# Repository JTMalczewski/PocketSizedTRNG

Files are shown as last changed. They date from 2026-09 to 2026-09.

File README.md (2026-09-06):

# Pocket-sized True Random Number Generator using weak radioactive source
Pocket-sized True Random Number Generator leverages radiation decay measured by a Geiger counter to produce high-quality entropy. The device processes these random physical events into cryptographically useful bitstreams directly on an RP2040 microcontroller - Raspberry Pi Pico H.

### Repository content

* `/models`: 3d-models used for printing devices case and double walled box for the radioactive isotope.

* `/code`: Full CircutPython code used in the device.

* `/sp800_22_tests`: implementation of the NIST SP800-22 Rev1a tests suite in python created by [dj-on-github](https://github.com/dj-on-github).

* `/data`: Samples of the random sequences generated by the device.

### Hardware configuration

* **Output**: Random data is piped securely to a host device over a USB CDC data connection.

* **Geiger Counter Interface**: Uses the RP2040's Programmable I/O (PIO) on pin GP0. A dedicated state machine runs at 100 MHz to measure the clock cycles between incoming radiation pulses. Device detects background radiation or radioactive isotope by Gravity Geiger Counter SEN0463 but any other detector that lowers the voltage on event detection will work.

* **Real-Time Clock and Local Storage**: An integrated Adafruit PiCowbell Adalogger with PCF8523 RTC module and SD slot communicates 
* * via I2C - pins GP4 and GP5 to timestamp logs and provide nonce to DRBG 
* * via GP16, GP17, GP18, GP19 to allow headless data collection.

### Entropy extraction & calibration

* **Von Neumann Debiasing**: An optional software flag applies a Von Neumann extractor to the raw interval bits, eliminating bias in older bits of the counter.

* **SD Logging**: The system can write raw cycle data and interval timestamps to a SD card for offline randomness collection.

* **TRNG**: Device can send generated bytes via USB port to be used as an entropy source to the operating system or to be gathered in a file.

### Cryptography & self-testing

* **Hash DRBG**: The device can optionally feed a built-in Deterministic Random Bit Generator. It gathers 55 bytes of pure entropy to seed the generator, outputting data in 1024-byte chunks.

* **Embedded Statistical Tests**: Implements on-the-fly health checks using Monobit, Frequency within Block, Runs, Longest Run, Serial, Approximate Entropy, and Cumulative Sums tests from NIST SP800-22 Rev1a test suite.

## Reading random bytes on Linux
Since the `boot.py` file enables both the console and the data channel (`usb_cdc.enable(console=True, data=True)`), the microcontroller will expose two separate serial ports when connected.

### 1. Identify the data port

After plugging in the device, open your terminal and list the connected serial devices:

```bash
ls -l /dev/ttyACM*
```

You will typically see two devices listed:

`/dev/ttyACM0` – The REPL console

`/dev/ttyACM1` – The data channel

### 2. Configure permissions and add packages

- Add your user to the dialout group. You must log out and log back in (or restart your computer) for this change to take effect.
```Bash
sudo usermod -aG dialout $USER
```
- Script below uses `serial` package. You can install it by running:
```bash
pip install pyserial
```

### 3. Read and print the data

Create a script with the following code to listen to the data channel and print the received bytes.
```py
Python

import serial

PORT = '/dev/ttyACM1' 
BAUDRATE = 115200 

try:
    with serial.Serial(PORT, BAUDRATE, timeout=1) as ser:
        print(f"Opened port {PORT}. Waiting for entropy from the Geiger counter...")
        
        while True:
            byte_data = ser.read(1)
            
            if byte_data:
                hex_val = byte_data.hex()
                int_val = int.from_bytes(byte_data, byteorder='big')
                print(f"Received byte: 0x{hex_val} (Dec: {int_val})")
                
except serial.SerialException as e:
    print(f"Serial port error: {e}")
except KeyboardInterrupt:
    print("\nStopped listening.")
```

### 4. Save the data
You can run the attached script using default settings to immediately start saving raw binary data to your working directory:

```bash
python read_bytes.py
```

**Command-Line Arguments**

| Argument | Short Flag | Description | Default Value |
| --- | --- | --- | --- |
| `--port` | `-p` | Defines the serial port the Geiger counter is connected to. | `/dev/ttyACM1`<br> |
| `--baudrate` | `-b` | Sets the serial baud rate. | `115200`<br> |
| `--output` | `-o` | Specifies the destination file path for the saved data. | `random_bytes.bin`<br> |
| `--format` | `-f` | Determines how the bytes are encoded in the output file. | `bin`<br> |
| `--verbose` | `-v` | Prints the hex and decimal values of each gathered byte to the console. | Disabled |

**Supported Output Formats (`-f`)**

* **`bin`**: Writes the raw binary byte stream to the file.
* **`hex`**: Converts the bytes into hexadecimal digits, outputting them at 32 bytes per line.
* **`asci`**: Maps the random bytes to printable ASCII characters (`chr(32 + (b % 95)`), saving 32 characters per line.
* **`dec`**: Outputs space-separated decimal numbers, formatting them with 16 values per line.
* **`bits`**: Saves the data as literal binary strings (0s and 1s), writing 8 bytes per line.

**Stopping the Capture**
The script will wait and listen for data indefinitely. Press `Ctrl+C` in your terminal to stop the process. The script will automatically flush any remaining buffered text data to your output file before exiting.

### 5. Test the randomness
 To perform full analysis on generated sequence run:
```bash
./sp800_22_tests/sp800_22_tests.py ./data/random_bytes.bin
```

## Feeding TRNG entropy to the Linux kernel
You can feed randomness directly into the Linux kernel to improve system cryptography using either a Python script or the standard Linux `rng-tools` daemon.

### Method 1: Python script

To increase the kernel's entropy pool, data must be injected using the `RNDADDENTROPY` system call. The following script batches the bytes from the serial port and injects them into `/dev/random`.

**Prerequisites:** You must run this script with `sudo` or as root.

```python
import serial
import fcntl
import struct

PORT = '/dev/ttyACM1' 
BAUDRATE = 115200 

# The ioctl code for RNDADDENTROPY on x86, x86_64, and ARM Linux
RNDADDENTROPY = 0x40085203 

try:
    dev_random = open('/dev/random', 'wb')
except PermissionError:
    print("Error: You must run this script as root to inject entropy.")
    exit(1)

try:
    with serial.Serial(PORT, BAUDRATE, timeout=1) as ser:
        print(f"Opened port {PORT}. Gathering entropy from Geiger counter...")
        
        buffer = b''
        chunk_size = 32
        while True:
            byte_data = ser.read(1)
            if byte_data:
                buffer += byte_data
                if len(buffer) >= chunk_size:
                    entropy_bits = len(buffer) * 8
                    buf_size = len(buffer)
                    fmt = f'ii{buf_size}s'
                    payload = struct.pack(fmt, entropy_bits, buf_size, buffer)
                    fcntl.ioctl(dev_random, RNDADDENTROPY, payload)
                    print(f"Injected {buf_size} bytes ({entropy_bits} bits of entropy) into the kernel.")
                    buffer = b''
                
except serial.SerialException as e:
    print(f"Serial port error: {e}")
except KeyboardInterrupt:
    print("\nStopped listening.")
finally:
    dev_random.close()
```

### Method 2: Using rngd

For long-term or production use, the standard Linux rngd (from rng-tools) is recommended. It runs continuously in the background and constantly performs FIPS 140-2 cryptographic tests on the incoming data stream to ensure the sensor hasn't failed or become biased.

#### 1. Install rng-tools:
```Bash

# Debian/Ubuntu
sudo apt install rng-tools

# RHEL/Fedora
sudo dnf install rng-tools
```
#### 2. Configure the serial port:
Set the correct baud rate and tell Linux not to parse the raw binary data for terminal control characters.

```Bash
sudo stty -F /dev/ttyACM1 115200 raw -echo
```
3. Run the Daemon:
Tell rngd to use the serial port as the hardware RNG source.
```Bash
sudo rngd -r /dev/ttyACM1 -f -v
```
(Omit the -f and -v flags to let it run silently in the background as a standard daemon).

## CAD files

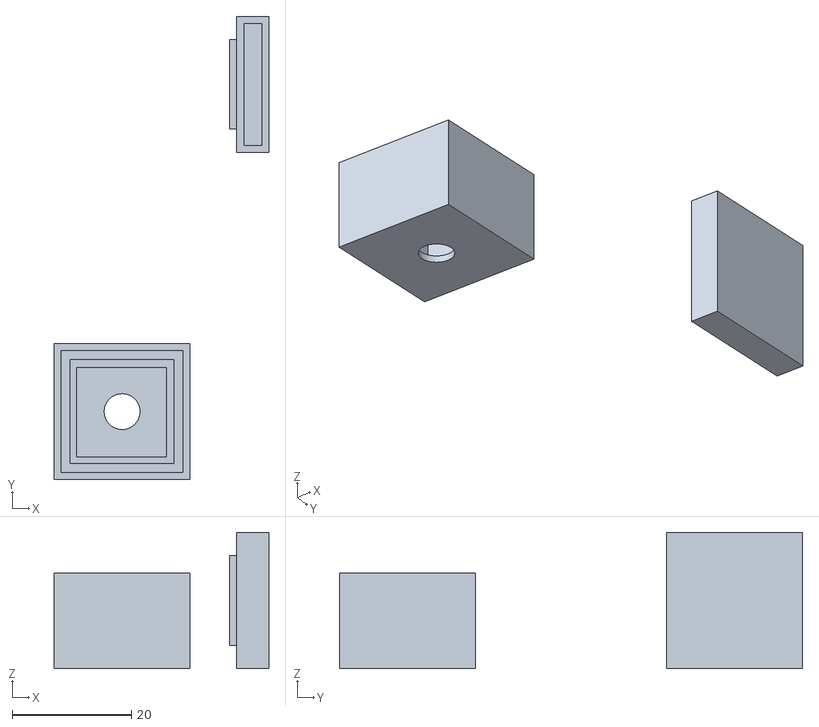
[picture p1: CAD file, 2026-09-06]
models/Isotop_container.stl
36.0 x 77.6 x 22.8

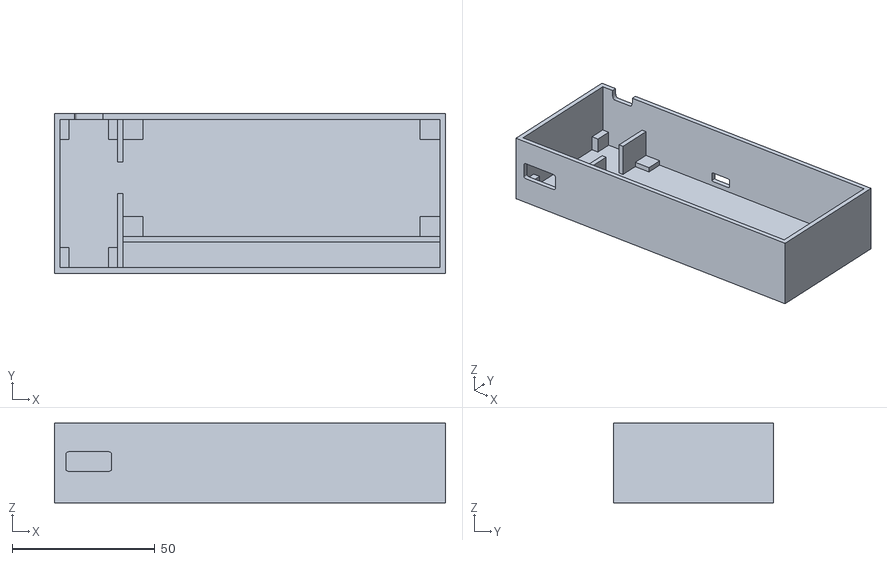
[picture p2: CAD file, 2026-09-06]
models/Gaiger_box.stl
137.0 x 56.0 x 28.0

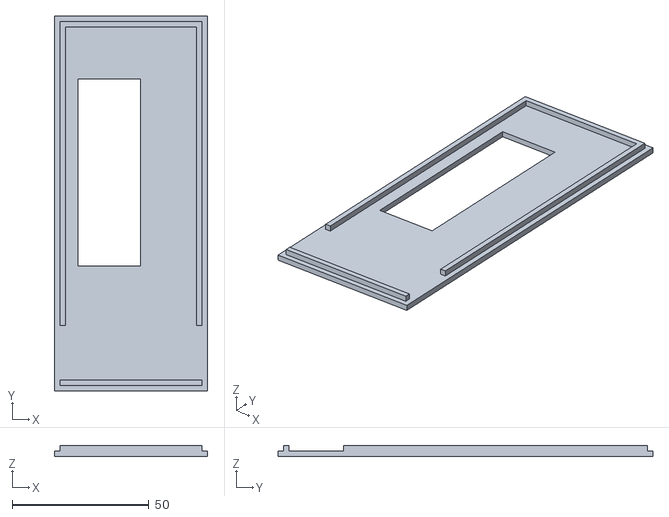
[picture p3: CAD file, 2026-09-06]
models/Gaiger_lid.stl
56.0 x 137.0 x 4.00

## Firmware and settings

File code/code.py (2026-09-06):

# SPDX-FileCopyrightText: 2017 ladyada for Adafruit Industries
# SPDX-License-Identifier: MIT

import time
import board
import busio
import rp2pio
import storage
import sdcardio
import array
from adafruit_pcf8523.pcf8523 import PCF8523
import digitalio
import sys
import usb_cdc
import monobit
import frequency_within_block
import runs
import longest_run
import serial
import approximate_entropy
import cumulative_sums
import HashDRBGMicro

# -------- Settings --------
VON_NEUMANN = True
WRITING = False
TRNG = True
TRNG_WRITING = False
LOGFILE = "/sd/Izotop_test_02_08_2026.csv"
TRNG_BIN_FILE = "/sd/TRND.bin"
CALIBRATION = False
BITS_TO_EXTRACT = 32

# -------- Test Settings --------
# TEST_MODE options:
# "NONE"     -> Tests disabled, data flows immediately without blocking.
# "INTERVAL" -> Run tests periodically every TEST_INTERVAL_BYTES generated.
# "RESEED"   -> Run tests every time before DRBG is instantiated or reseeded.
TEST_MODE = "RESEED"
TEST_INTERVAL_BYTES = 10000
N_BITS_TO_CHECK = 1000

# -------- DRBG settings --------
USE_DRBG = True
DRBG_ENTROPY_REQUIRED = 55
DRBG_OUTPUT_BYTES = 1024
PERSONALIZATION_STRING = b"Izotop_RP2040_TRNG_v1"
RESEED_INTERVAL = 1000

# -------- SD Card --------
SD_CS = board.GP17
spi = busio.SPI(board.GP18, board.GP19, board.GP16)
sdcard = sdcardio.SDCard(spi, SD_CS)
vfs = storage.VfsFat(sdcard)

if WRITING or TRNG_WRITING:
    try:
        storage.mount(vfs, "/sd")
        print("sd card mounted")
    except ValueError:
        print("no SD card")

# -------- Time --------
I2C = busio.I2C(board.GP5, board.GP4)
rtc = PCF8523(I2C)
set_time = False
t = rtc.datetime
days = ("Sunday", "Monday", "Tuesday", "Wednesday", "Thursday", "Friday", "Saturday")
if set_time:   # change to True if you want to write the time!
    #                     year, mon, date, hour, min, sec, wday, yday, isdst
    t = time.struct_time((2025,  12,   9,   22,  33,  25,    1,   -1,    -1))

    print("Setting time to:", t)
    rtc.datetime = t
    print()

def rtc_timestamp(rtc):
    t = rtc.datetime
    return (
        f"{t.tm_year:04d}-{t.tm_mon:02d}-{t.tm_mday:02d},"
        f"{t.tm_hour:02d}:{t.tm_min:02d}:{t.tm_sec:02d}"
    )

# -------- Logs --------
#  initial write to the SD card on startup
if WRITING:
    try:
        with open("/sd/temp.txt", "a") as f:
            f.write('The date is {} {}/{}/{}\n'.format(days[t.tm_wday], t.tm_mon, t.tm_mday, t.tm_year))
            f.write('Start time: {}:{}:{}\n'.format(t.tm_hour, t.tm_min, t.tm_sec))
            f.write('Temp,Time\n')
            print("initial write to SD card complete, starting to log")
    except ValueError:
        print("initial write to SD card failed - check card")


# -------- Gaiger Configuration --------
period_between_lows_bin = array.array("H", [
    0xa02b, # 0: mov x, !null
    # --- MAIN LOOP ---
    0x00c6, # 1: jmp pin, 6

    # --- IF LOW SIGNAL DETECTED ---
    0xa0c1, # 2: mov isr, x
    0x8020, # 3: push
    0xa02b, # 4: mov x, !null
    0x20a0, # 5: wait 1 pin 0

    # --- COUNTING ---
    0x0041, # 6: jmp x--, 1
])

# - For 100 MHz (1 loop = 1 us)
# - unsigned 32-int counter: 4294967294
# - one loop takes 2 clock ticks
# - overflow after 86 s

measure = rp2pio.StateMachine(
    period_between_lows_bin,
    frequency=100_000_000,
    first_in_pin=board.GP0,
    jmp_pin=board.GP0,
    in_pin_count=1
)

buf = array.array("I", [0])

# -------- TRNG --------
_entropy_byte = 0
_bit_count = 0
_vn_prev_cycles = None

def get_entropy_bytes_and_bits(cycles, num_bits):
    global _entropy_byte, _bit_count, _vn_prev_cycles
    completed_bytes = []
    valid_bits = []

    if VON_NEUMANN:
        if _vn_prev_cycles is None:
            _vn_prev_cycles = cycles
        else:
            for i in range(num_bits):
                b1 = (_vn_prev_cycles >> i) & 1
                b2 = (cycles >> i) & 1

                valid_bit = None
                if b1 == 0 and b2 == 1:
                    valid_bit = 0
                elif b1 == 1 and b2 == 0:
                    valid_bit = 1

                if valid_bit is not None:
                    _entropy_byte = (_entropy_byte << 1) | valid_bit
                    _bit_count += 1
                    valid_bits.append(valid_bit)

                    if _bit_count == 8:
                        completed_bytes.append(_entropy_byte)
                        _entropy_byte = 0
                        _bit_count = 0

            _vn_prev_cycles = None
    else:
        for i in range(num_bits):
            bit = (cycles >> i) & 1
            _entropy_byte = (_entropy_byte << 1) | bit
            _bit_count += 1
            valid_bits.append(bit)

            if _bit_count == 8:
                completed_bytes.append(_entropy_byte)
                _entropy_byte = 0
                _bit_count = 0

    return completed_bytes, valid_bits


def run_all_tests(bits_to_test):
    print(f"\n--- Running tests ({len(bits_to_test)} bits) ---")

    success_mb, p, _ = monobit.monobit_test(bits_to_test)
    print(f"-> Monobit Result: {'PASSED' if success_mb else 'FAILED'} (p-value: {p:.5f})")

    success_blk, p_blk, _ = frequency_within_block.frequency_within_block_test(bits_to_test)
    print(f"-> Freq Within Block Result: {'PASSED' if success_blk else 'FAILED'} (p-value: {p_blk:.5f})")

    success_runs, p_runs, _ = runs.runs_test(bits_to_test)
    print(f"-> Runs Result: {'PASSED' if success_runs else 'FAILED'} (p-value: {p_runs:.5f})")

    success_lr, p_lr, _ = longest_run.longest_run_ones_in_a_block_test(bits_to_test)
    print(f"-> Longest Run Result: {'PASSED' if success_lr else 'FAILED'} (p-value: {p_lr:.5f})")

    success_serial, _, p_list_serial = serial.serial_test(bits_to_test)
    print(f"-> Serial Result: {'PASSED' if success_serial else 'FAILED'} (P1: {p_list_serial[0]:.5f}, P2: {p_list_serial[1]:.5f})")

    success_ae, p_ae, _ = approximate_entropy.approximate_entropy_test(bits_to_test)
    print(f"-> Approx Entropy Result: {'PASSED' if success_ae else 'FAILED'} (p-value: {p_ae:.5f})")

    success_cusum, _, p_list_cusum = cumulative_sums.cumulative_sums_test(bits_to_test)
    print(f"-> Cumulative Sums Result: {'PASSED' if success_cusum else 'FAILED'} (Fwd: {p_list_cusum[0]:.5f}, Bwd: {p_list_cusum[1]:.5f})")

    print("-----------------------------------------\n")
    return (success_mb and success_blk and success_runs and success_lr and
            success_serial and success_ae and success_cusum)

# -------- TRNG Calibration --------
if CALIBRATION:
    print("Starting calibration - counting pulses for 10 seconds (RTC)...")
    total_cycles = 0
    counts = 0

    while measure.in_waiting:
        measure.readinto(buf)

    start_time = time.mktime(rtc.datetime)
    current_time = start_time

    while (current_time - start_time) < 10:
        if measure.in_waiting:
            measure.readinto(buf)
            raw_value = buf[0]
            max_uint32 = 0xFFFFFFFF
            total_cycles += (max_uint32 - raw_value)
            counts += 1
        else:
            current_time = time.mktime(rtc.datetime)

    if counts > 0:
        avg_cycles = total_cycles // counts
        print(f"Calibration finished. {counts} pulses recorded.")
        print(f"Average number of cycles between pulses: {avg_cycles}")
    else:
        avg_cycles = 100_000_000
        print("No pulses during calibration. Assuming background radiation.")

    if avg_cycles < 50_000:
        BITS_TO_EXTRACT = 6
    elif avg_cycles < 500_000:
        BITS_TO_EXTRACT = 6
    elif avg_cycles < 5_000_000:
        BITS_TO_EXTRACT = 8
    else:
        BITS_TO_EXTRACT = 8

    print(f"Set to extract {BITS_TO_EXTRACT} bits from each read.")
else:
    print(f"Calibration skipped. Defaulted to {BITS_TO_EXTRACT} bits extraction.")

# -------- DRBG Setup --------
if USE_DRBG:
    drbg = HashDRBGMicro.HashDRBGMicro()
drbg_is_seeded = False
raw_entropy_buffer = bytearray(DRBG_ENTROPY_REQUIRED)
entropy_index = 0

# -------- Main State --------
log_buffer = ""
trng_buffer = bytearray()
last_save_time = time.monotonic()
SAVE_INTERVAL = 5.0

# Testing state variables
testing_active = False
bytes_since_last_test = 0
reseed_test_passed = False
test_bit_buffer = []

if WRITING:
    try:
        with open(LOGFILE, "a") as f:
            if f.tell() == 0:
                f.write("date,time,cycles,delta_ns\n")
    except Exception as e:
        print("SD init error for CSV:", e)

if TRNG_WRITING:
    print("Writing TRNG bytes to BIN file activated.")

print("I'm starting to collect data...")

while True:
    if measure.in_waiting:
        measure.readinto(buf)
        raw_value = buf[0]
        max_uint32 = 0xFFFFFFFF
        cycles = (max_uint32 - raw_value)

        new_bytes = []
        new_bits = []
        if TRNG or TRNG_WRITING or USE_DRBG:
            new_bytes, new_bits = get_entropy_bytes_and_bits(cycles, BITS_TO_EXTRACT)

        if WRITING:
            delta_ns = cycles * 20
            ts = rtc_timestamp(rtc)
            log_buffer += f"{ts},{cycles},{delta_ns}\n"

        # Evaluate if we need to trigger the testing phase
        if TEST_MODE == "INTERVAL":
            if bytes_since_last_test >= TEST_INTERVAL_BYTES:
                testing_active = True
        elif TEST_MODE == "RESEED":
            drbg_needs_seed = USE_DRBG and (not drbg_is_seeded or drbg.reseed_counter >= RESEED_INTERVAL)
            if drbg_needs_seed and not reseed_test_passed:
                testing_active = True
        else: # "NONE"
            testing_active = False

        # If testing phase is active, divert entropy strictly to the test buffer
        if testing_active:
            test_bit_buffer.extend(new_bits)
            if len(test_bit_buffer) >= N_BITS_TO_CHECK:
                bits_to_test = test_bit_buffer[:N_BITS_TO_CHECK]
                del test_bit_buffer[:N_BITS_TO_CHECK]

                all_passed = run_all_tests(bits_to_test)

                if all_passed:
                    print("-> ALL TESTS PASSED. Resuming output...\n")
                    testing_active = False
                    if TEST_MODE == "INTERVAL":
                        bytes_since_last_test = 0
                    elif TEST_MODE == "RESEED":
                        reseed_test_passed = True
                else:
                    print("-> TESTS FAILED. Collecting a new sample...\n")
                    test_bit_buffer = [] # Reset and test next chunk

            # Skip output routing while testing is gathering bits
            pass

        else:
            # We are NOT testing - securely route the stream out
            if TEST_MODE == "INTERVAL":
                bytes_since_last_test += len(new_bytes)

            valid_bytes = new_bytes

            if valid_bytes and (TRNG or TRNG_WRITING or USE_DRBG):
                bytes_to_export = valid_bytes

                if USE_DRBG:
                    for b in valid_bytes:
                        if entropy_index < DRBG_ENTROPY_REQUIRED:
                            raw_entropy_buffer[entropy_index] = b
                            entropy_index += 1

                    bytes_to_export = b"" # Suppress output until the DRBG triggers
                    needs_reseed = drbg_is_seeded and (drbg.reseed_counter >= RESEED_INTERVAL)

                    if (not drbg_is_seeded) or needs_reseed:
                        if entropy_index >= DRBG_ENTROPY_REQUIRED:
                            seed_chunk = bytes(raw_entropy_buffer)
                            entropy_index = 0

                            if not drbg_is_seeded:
                                rtc_nonce = rtc_timestamp(rtc).encode('utf-8')
                                drbg.instantiate(seed_chunk, rtc_nonce, PERSONALIZATION_STRING)
                                drbg_is_seeded = True
                            else:
                                drbg.reseed(seed_chunk)

                            # Reset reseed test requirement for the next time it's needed
                            reseed_test_passed = False

                    if drbg_is_seeded:
                        bytes_to_export = drbg.generate(DRBG_OUTPUT_BYTES)

                if TRNG and bytes_to_export:
                    if usb_cdc.data:
                        usb_cdc.data.write(bytes(bytes_to_export))

                if TRNG_WRITING and bytes_to_export:
                    trng_buffer.extend(bytes_to_export)

        # Continual SD Card flushing check
        if WRITING or TRNG_WRITING:
            current_time = time.monotonic()
            if (current_time - last_save_time) >= SAVE_INTERVAL:
                if WRITING and log_buffer:
                    try:
                        with open(LOGFILE, "a") as f:
                            f.write(log_buffer)
                        log_buffer = ""
                        print('CSV Buffer saved')
                    except Exception as e:
                        print(f"Error saving CSV to SD: {e}")

                if TRNG_WRITING and trng_buffer:
                    try:
                        with open(TRNG_BIN_FILE, "ab") as f:
                            f.write(trng_buffer)
                        trng_buffer = bytearray()
                        print('TRNG Buffer saved')
                    except Exception as e:
                        print(f"Error saving BIN to SD: {e}")

                last_save_time = current_time

    time.sleep(0.001)

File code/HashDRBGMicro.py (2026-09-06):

import _sha256

class HashDRBGMicro:
    def __init__(self):
        self.hash_len = 32
        self.seed_len = 55
        self.modulus = 1 << (self.seed_len * 8)

        self.V = 0
        self.C = 0
        self.reseed_counter = 0

    def _hash_df(self, input_string: bytes, no_of_bytes_to_return: int) -> bytes:
        temp = bytearray()
        counter = 1
        no_of_bits_to_return = no_of_bytes_to_return * 8
        bits_bytes = no_of_bits_to_return.to_bytes(4, 'big')

        while len(temp) < no_of_bytes_to_return:
            h = _sha256.sha256()
            h.update(bytes([counter]))
            h.update(bits_bytes)
            h.update(input_string)
            temp.extend(h.digest())
            counter += 1

        return bytes(temp[:no_of_bytes_to_return])

    def instantiate(self, entropy: bytes, nonce: bytes = b"", personalization_string: bytes = b""):
        seed_material = entropy + nonce + personalization_string

        seed = self._hash_df(seed_material, self.seed_len)
        self.V = int.from_bytes(seed, 'big')

        c_input = b'\x00' + seed
        c_bytes = self._hash_df(c_input, self.seed_len)
        self.C = int.from_bytes(c_bytes, 'big')

        self.reseed_counter = 1

    def reseed(self, entropy: bytes, additional_input: bytes = b""):
        seed_material = (b'\x01' +
                         self.V.to_bytes(self.seed_len, 'big') +
                         entropy +
                         additional_input)

        seed = self._hash_df(seed_material, self.seed_len)
        self.V = int.from_bytes(seed, 'big')

        c_input = b'\x00' + seed
        c_bytes = self._hash_df(c_input, self.seed_len)
        self.C = int.from_bytes(c_bytes, 'big')

        self.reseed_counter = 1

    def _hash_gen(self, requested_bytes: int) -> bytes:
        m = (requested_bytes + self.hash_len - 1) // self.hash_len
        data = self.V
        W = bytearray()

        for _ in range(m):
            h = _sha256.sha256()
            h.update(data.to_bytes(self.seed_len, 'big'))
            W.extend(h.digest())
            data = (data + 1) % self.modulus

        return bytes(W[:requested_bytes])

    def generate(self, requested_bytes: int, additional_input: bytes = b"") -> bytes:
        if self.reseed_counter > 281474976710656:
            raise RuntimeError("Reseed required")

        if additional_input:
            h = _sha256.sha256()  # <-- Updated call
            h.update(b'\x02' + self.V.to_bytes(self.seed_len, 'big') + additional_input)
            w = int.from_bytes(h.digest(), 'big')
            self.V = (self.V + w) % self.modulus

        rnd_bytes = self._hash_gen(requested_bytes)

        h = _sha256.sha256()  # <-- Updated call
        h.update(b'\x03' + self.V.to_bytes(self.seed_len, 'big'))
        H = int.from_bytes(h.digest(), 'big')

        self.V = (self.V + H + self.C + self.reseed_counter) % self.modulus
        self.reseed_counter += 1

        return rnd_bytes
